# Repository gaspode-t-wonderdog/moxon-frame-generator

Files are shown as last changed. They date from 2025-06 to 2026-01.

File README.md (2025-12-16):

# Summary

This is a simple OpenSCAD script you can use to generate a frame for a moxon rectangle antenna and print it on your 3D printer.

"The Moxon rectangle is a 2-element parasitical beam or unidirectional antenna about 70% the length of a full size 2-element Yagi of standard driver-reflector design."
according to antenna2.net and conveniently comes with 50 Ohms impedance right out the box.

The original intention was to use this to assemble cheap and simple antenna kits for foxhunts with kids which can be attached right away to your handheld radio, but it's not limited to this usecase.

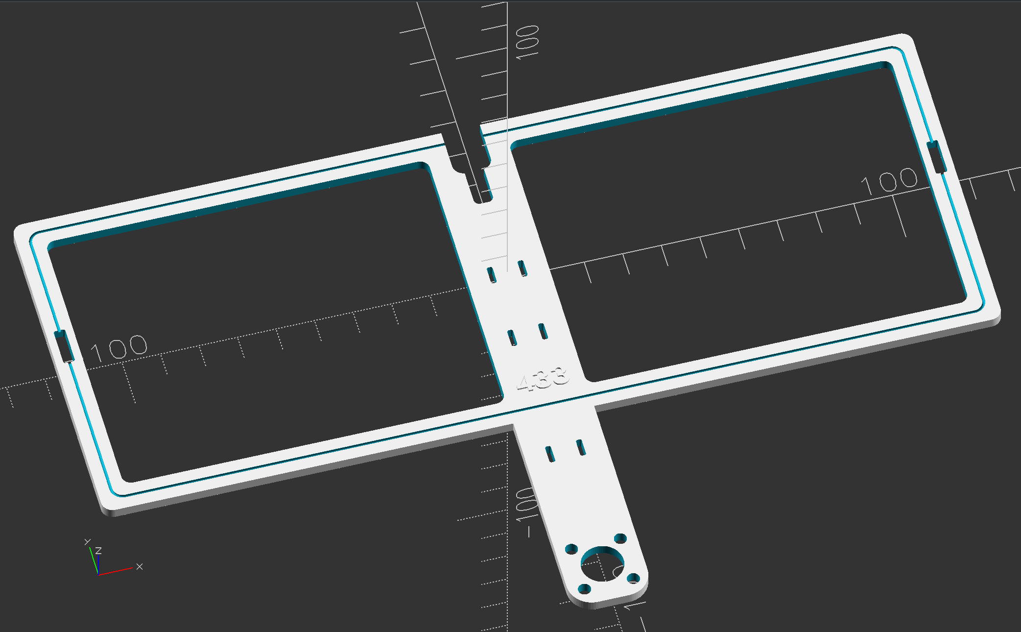
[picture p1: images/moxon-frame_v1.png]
Moxon frame v1


# Further information

The script also lets you change variables, which should be self-explaining, except the "connector type" - 
the idea was to heat up and bend the end of the handle upwards, but you can also choose to have a simple screw hole for mounting it somewhere.

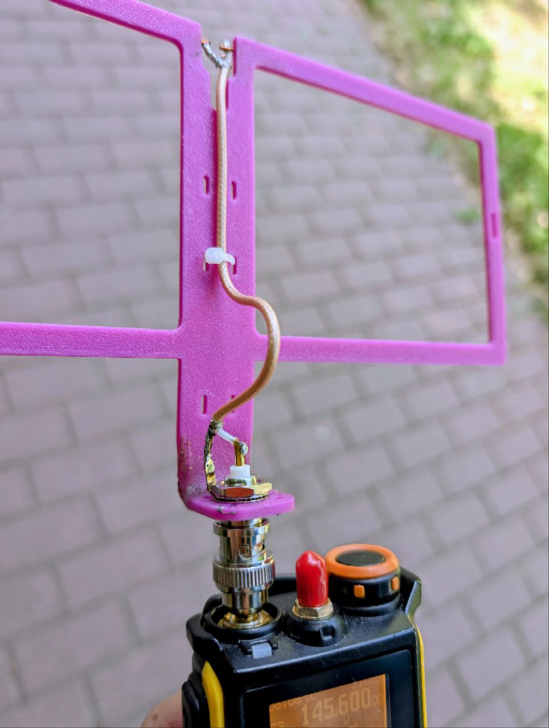
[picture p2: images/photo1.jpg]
prototype


I'm open for suggestions for better mounting options.

## difference between versions

The first version had a flat wire channel and was working quite well with thicker
copper wires but sometimes needed some glue for the wire to stay in.

The second version has a round recessed channel where the wire holds in by itself - and adds a hole where you can use side cutters to trim the wire.

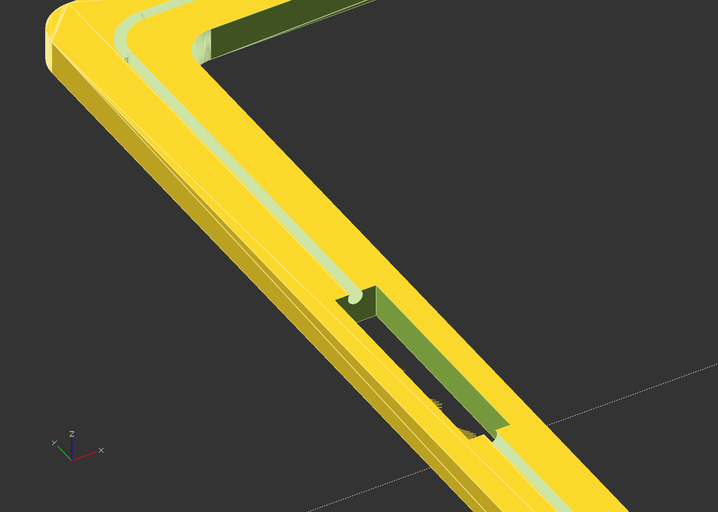
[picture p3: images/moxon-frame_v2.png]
Moxon frame v2


This works better if you use a layer height <=0.15mm for printing.

For version 3 @gretel (DO2THX) added the calculation logic (based on the online calculator from antenna2.net) to the OpenSCAD script.

I still like to keep version 2 around, in case anyone wants to experiment with their own values.

## about correction factors

While measuring our first antennas we found that they were way off - of course covering the antenna in plastic changes the frequency it operates at due to the dielectric property of the additional plastic. 
As the polymer increases the capacitance significantly, the antenna experiences capacitive shortening.

So we need a correction factor (or velocity factor) to achieve the desired resonating frequency.

## printing

Either you trust our conclusion (see measurements below), that it always ends up with a factor of around 1.1, or you have to figure it out by yourself.

To do so the best strategy would be:

- For Version 2 calculate the antenna for your desired frequency with your favourite online calculator (I'd recommend https://antenna2.github.io/cebik/content/moxon/moxpage.html),
enter the values inside the script
- For Version 3 enter the frequency right on top and set the "correction_factor" to 1.0

Print and assemble the antenna, measure it with a VNA to find out at which frequency it plays best and divide desired_frequency / actual_frequency - that's your correction factor.

Now reprint by either calculating it for your_desired_frequency * factor or simply change the "correction_factor" in Version 3 of the script.

## connectors

There are various connector types and I only implemented those we had lying around, but it's also quite easy to add your own.
I'll add pics of the current types later.

## Assembly

- To set the wire you should roughly prepare the needed lenght first, and consider to prepare the wire for soldering beforehand.
	-   To set the wire inside the groove, start at the feedpoint, then firmly press the conductor down with the help of a solid plastic object.
    follow the groove all the way around and pay great attention to detail at the bends (those tend to be stubborn)
	- If it doesn't fit perfectly, adjust the "dia" variable in v2 or the "wire_tolerance" variable in version 3 and reprint.

- Cutting the conductor. Cutting the conductor at it's designated spots is simply done with flush cutters.
    press firmly against the frame so there is no overhang of wire within the gap. (in some cases, you might want to temporarily remove the wire)
	- Depending on the frequency, cutting it flush against the gap, is more difficult. the cut needs to be square to be most acurate.

- Optionally bend the boom at the end to attach the frame directly to your handheld radio. Heat the boom and bend to taste (OwO)
	- Use a heat gun or a lighter (this will take time in any way you do it - don't rush it or it'll char - as seen in the picture above)

- After setting the connector, you need to bridge the distance with 50 Ohm coaxial conductor like RG58 RG174 or similar. Take time for soldering.

I'll also add some detailed pictures later.

# Measurements

We did some measurements to figure out the correction factor for different frequencies and we planned to do more for various materials, filament colors and so on...
but due to a lack of time that didn't happen yet :) - but for most materials we ended up with a factor of around 1.1
(only higher frequencies (> 1 GHz) seem to be a bit off).

Here are some measurements for eSUN-PLA+:

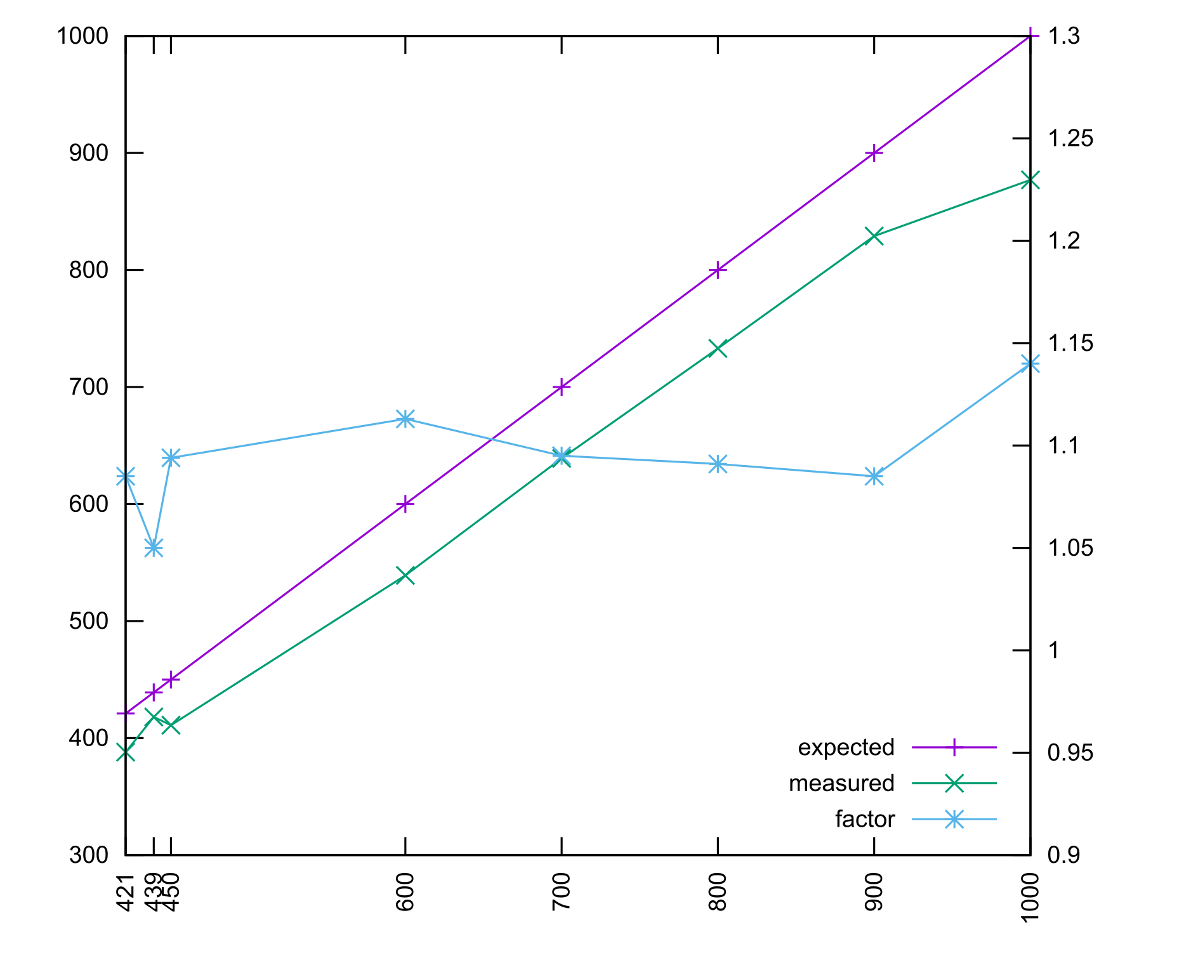
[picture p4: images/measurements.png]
gnuplot


# kthxbye

I'll happily take your input and suggestions, especially about mounting, adding more connectors and so on.

There's also a cubical quad antenna in the making, using similiar techniques. Stay tuned!

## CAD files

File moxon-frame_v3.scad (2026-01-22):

// "Self-calculating Moxon antenna frame generator"
// Original idea: https://www.thingiverse.com/thing:2068392
// Based on empirical formulas by L.B. Cebik (W4RNL)
// https://www.antenna2.net/cebik/books/Moxon-Rectangle-Notes.pdf
// 2025 DO2THX (tom@jitter.eu)
// License: CC-BY-NC-SA

// ===== USER ADJUSTABLE PARAMETERS =====

// === BASIC ANTENNA DESIGN ===
// Design frequency in MHz
freq_mhz = 433;
// Wire diameter in mm
wire_dia_mm = 1.0;

// === MATERIAL PROPERTIES ===
correction_factor = 1.1;

// === FRAME CONSTRUCTION ===
// Frame wall thickness (mm)
frame_width = 7.0;
// Frame height/thickness (mm)
frame_thickness = 2.5;
// Corner rounding radius (mm)
corner_radius = 3.0;

// === WIRE CHANNEL ===
// Wire clearance tolerance (mm) for 3D-printing
wire_tolerance = 0;
// Channel depth as fraction of wire diameter
wire_depth_ratio = 0.33;

// === HANDLE & MOUNTING ===
// Handle length (mm) - set to 0 to disable
handle_length = 60;
// Handle width (mm)
handle_width = 21;

// === CONNECTOR ===
// RF connector type (see README)
connector = "bnc"; // ["none", "sma", "sma2", "bnc", "bnc2", "screw"]
// Screw diameter (mm) - for screw connector type
screw_dia = 4.4;

// === APPEARANCE ===
// Frequency label text size (mm)
text_size = 7;
// Text font
text_font = "Liberation Sans:style=Bold";
// Show frequency label on handle
show_frequency_text = true;

// === RENDERING QUALITY ===
// Circle resolution - higher values = smoother curves but slower rendering
$fn = 64;

// ===== DERIVED PARAMETERS (DO NOT EDIT) =====

function moxon_calculate_dimensions(f_mhz, dia_mm) = 
	let(
		// Calculate wavelength in mm
		c = 299792458,              // Speed of light in m/s
		wavelength_mm = (c / (f_mhz * 1000000)) * 1000,

		// Convert wire diameter to wavelengths
		dia_wavelengths = dia_mm / wavelength_mm,

		// Validate wire diameter range (1E-5 to 1E-2 wavelengths)
		dia_wl_min = 1e-5,
		dia_wl_max = 1e-2,
		dia_valid = (dia_wavelengths >= dia_wl_min && dia_wavelengths <= dia_wl_max),

		// Use log10 of diameter in wavelengths
		log_dia = log(dia_wavelengths) / log(10),  // Convert to common log (base 10)

		// Cebik's empirical coefficients for 50-ohm Moxon
		// A dimension coefficients
		AA = -0.0008571428571,
		AB = -0.009571428571,
		AC = 0.3398571429,

		// B dimension coefficients
		BA = -0.002142857143,
		BB = -0.02035714286,
		BC = 0.008285714286,

		// C dimension coefficients
		CA = 0.001809523381,
		CB = 0.01780952381,
		CC = 0.05164285714,

		// D dimension coefficients
		DA = 0.001,
		DB = 0.07178571429,

		// Calculate dimensions in wavelengths using Cebik's formulas
		A_wl = (AA * pow(log_dia, 2)) + (AB * log_dia) + AC,
		B_wl = (BA * pow(log_dia, 2)) + (BB * log_dia) + BC,
		C_wl = (CA * pow(log_dia, 2)) + (CB * log_dia) + CC,
		D_wl = (DA * log_dia) + DB,
		E_wl = B_wl + C_wl + D_wl,

		// Convert to millimeters
		A_mm = A_wl * wavelength_mm,
		B_mm = B_wl * wavelength_mm,
		C_mm = C_wl * wavelength_mm,
		D_mm = D_wl * wavelength_mm,
		E_mm = E_wl * wavelength_mm,

		// Calculate some useful metrics
		boom_length_wl = E_wl,
		total_wire_length_mm = 2 * (A_mm + E_mm - 2 * C_mm),  // Approximate wire length
		compactness = A_wl / 0.5  // Compared to half-wave dipole
	)
	[A_mm, B_mm, C_mm, D_mm, E_mm, wavelength_mm, dia_valid, boom_length_wl, total_wire_length_mm, compactness];

// Calculate the actual dimensions
calc_result = moxon_calculate_dimensions(freq_mhz * correction_factor, wire_dia_mm);
A = calc_result[0];
B = calc_result[1];
C = calc_result[2];
D = calc_result[3];
E = calc_result[4];

wavelength = calc_result[5];
diameter_valid = calc_result[6];
boom_length_wavelengths = calc_result[7];
wire_length_mm = calc_result[8];
compactness_factor = calc_result[9];

// Wire channel parameters
wire_channel_dia = wire_dia_mm + wire_tolerance;	// Add tolerance for 3D printing
wire_depth = wire_dia_mm * wire_depth_ratio;

// Verbose output
echo(str("=== MOXON CALCULATOR RESULTS ==="));
echo(str("Design frequency: ", freq_mhz, " MHz"));
echo(str("Wire diameter: ", wire_dia_mm, " mm (", round(wire_dia_mm/wavelength * 1000000)/1000000, " λ)"));
echo(str(""));
echo(str("Calculated dimensions:"));
echo(str("A (width): ", round(A*100)/100, " mm (", round(A/wavelength*1000)/1000, " λ)"));
echo(str("B (driver tail): ", round(B*100)/100, " mm"));
echo(str("C (gap): ", round(C*100)/100, " mm")); 
echo(str("D (reflector tail): ", round(D*100)/100, " mm"));
echo(str("E (height): ", round(E*100)/100, " mm (", round(E/wavelength*1000)/1000, " λ)"));
echo(str(""));
echo(str("Additional info:"));
echo(str("Wavelength: ", round(wavelength*100)/100, " mm"));
echo(str("Estimated wire length: ", round(wire_length_mm), " mm"));
echo(str("Compactness: ", round(compactness_factor*100), "% of dipole width"));
echo(str("Wire diameter valid: ", diameter_valid ? "✓" : "⚠ Outside 1E-5 to 1E-2 λ range"));

// Validation warnings
if (!diameter_valid) {
	echo(str("⚠ WARNING: Wire diameter outside validated range!"));
	echo(str("   Formulas valid for diameters 1E-5 to 1E-2 wavelengths"));
	echo(str("   Current: ", round(wire_dia_mm/wavelength * 1000000)/1000000, " λ"));
}

// ===== 3D MODEL GENERATION =====

difference() {
	union() {
		// base shape
		linear_extrude(frame_thickness)
			fillet_o(3) fillet_i(1.5)
				base();

		// Frequency text on handle near connector
		if (show_frequency_text) {
			translate([0, -(E/2 - 5), frame_thickness])
				linear_extrude(0.5) {
					text(str(freq_mhz), size=text_size, font=text_font, halign = "center");
				}
		}
	}

	// Wire channels - vertical sides
	translate([-A/2, E/2 - corner_radius, frame_thickness-wire_depth])
		rotate([90, 0, 0]) linear_extrude(E - corner_radius*2) circle(wire_channel_dia/2);
	translate([A/2, E/2 - corner_radius, frame_thickness-wire_depth])
		rotate([90, 0, 0]) linear_extrude(E - corner_radius*2) circle(wire_channel_dia/2);

	// Wire channels - horizontal sides
	translate([-A/2 + corner_radius, E/2, frame_thickness-wire_depth])
		rotate([0, 90, 0]) linear_extrude(A - corner_radius*2) circle(wire_channel_dia/2);
	translate([-A/2 + corner_radius, -E/2, frame_thickness-wire_depth])
		rotate([0, 90, 0]) linear_extrude(A - corner_radius*2) circle(wire_channel_dia/2);

	// Wire channel rounded corners
	translate([-A/2 + corner_radius, E/2 - corner_radius, frame_thickness-wire_depth])
		rotate([0, 0, 90]) rotate_extrude(angle=90) translate ([corner_radius,0,0]) circle(wire_channel_dia/2);
	translate([A/2 - corner_radius, E/2 - corner_radius, frame_thickness-wire_depth])
		rotate_extrude(angle=90) translate ([corner_radius,0,0]) circle(wire_channel_dia/2);
	translate([-A/2 + corner_radius, -E/2 + corner_radius, frame_thickness-wire_depth])
		rotate([0, 0, 180]) rotate_extrude(angle=90) translate ([corner_radius,0,0]) circle(wire_channel_dia/2);
	translate([A/2 - corner_radius, -E/2 + corner_radius, frame_thickness-wire_depth])
		rotate([0, 0, 270]) rotate_extrude(angle=90) translate ([corner_radius,0,0]) circle(wire_channel_dia/2);

	// left wire endstop
	translate([-(A/2 +  wire_channel_dia/2 + 1), E/2 - B - C, 0])
		cube(size=[ wire_channel_dia + 2, C, frame_thickness]);
	// right wire endstop
	translate([(A/2 -  wire_channel_dia/2 - 1), E/2 - B - C, 0])
		cube(size=[wire_channel_dia + 2, C, frame_thickness]);

	// Big notch for wire insertion
	translate([0, E/2+frame_width/2, 0])
		rcube([10, 20+frame_width, frame_thickness], 3, true, false);

	// Smaller notch for wire routing
	translate([0, E/2, 0])
		rcube([5, 40, frame_thickness], 1.5, true, false);

	// Holes for cable ties (scaled with antenna size)
	if (E > 80) {
		cable_ties(4);
		translate([0, -20, 0])
			cable_ties(4);
	}
	else if (E > 40) {
		translate([0, -7, 0])
			cable_ties(4);
	}
	if (handle_length > 30) {
		translate([0, -(E/2) - 15, 0])
			cable_ties(4);
	}

	// Holes for mounting a connector
	if (handle_length > 0) {
		translate([0, -E/2 - frame_width - handle_length + 14, 0])
			connectors();
	}
}

module base() {
	difference() {
		// outer roundtangle
		square([A + frame_width, E + frame_width], center=true);
		// cutout
		square([(A - frame_width), E - frame_width], center=true);
	}

	// handle
	translate([0, -handle_length/2, 0])
		fillet_o(6)
			square([handle_width, E + handle_length + frame_width], center=true);
}

module cable_ties(spacing) {
	translate([-spacing, 0, 0])
		rcube([1.5, 5, frame_thickness], 0.5, true, false);
	translate([spacing, 0, 0])
		rcube([1.5, 5, frame_thickness], 0.5, true, false);
}
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

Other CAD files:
moxon-frame_v2.scad

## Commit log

2025-06-20 v2: fix rotate_extrude, angle parameter was missing (working in 2025-snapshot, though)
    [moxon-frame_v2.scad]
2025-08-10 v1/v2: apply missing xy_center parameter in rcube() function (should affect nothing, but it's mandatory for a v3-version @gretel is working on)
    [moxon-frame_v1.scad, moxon-frame_v2.scad]
2025-12-13 rm'd version 1: maintaining that old version doesn't make any sense
    [moxon-frame_v1.scad]
2025-12-13 fixed measurements+placement for the 4-hole bnc connector
    [moxon-frame_v2.scad]
2025-12-13 added more connectors - TODO: add description + pictures TO README
    [moxon-frame_v2.scad]
2025-12-13 adding 0.1 mm to the wire diameter was way too much, don't need that on my printer - people have to figure it out themselves
    [moxon-frame_v2.scad]
2025-12-13 improve text generation
    [moxon-frame_v2.scad]
2025-12-13 better default values + comments
    [moxon-frame_v2.scad]
2025-12-15 correct some miscalculations in connector module
    [moxon-frame_v2.scad]
2025-12-15 merged and added version 3, a "self calculating" version based on W4RNLs calculator from antenna2.net done by @gretel (DO2THX)
    additional notes:
    - squished some bugs
    - simplified the correction logic again, because I'm not convinced that
    it's an improvement over having a single factor
    (and the resulting antennas were way off anyway)
    - openSCADs editor still sucks and I reformatted the code to match
    version 2 :)
    [moxon-frame_v3.scad]
2025-12-16 restructured README, added printing and assembling sections
2026-01-17 gnenerate base shape in 2D, which leads to more consistent fillets also matched default values in v3 to v2
    [moxon-frame_v2.scad, moxon-frame_v3.scad]
2026-01-17 removed argument name for translate, it's optional and useless :)
    [moxon-frame_v2.scad, moxon-frame_v3.scad]
2026-01-17 v3: I think it's better not having too much roundness here
    [moxon-frame_v3.scad]
2026-01-22 slightly better notch placement
    [moxon-frame_v2.scad, moxon-frame_v3.scad]
